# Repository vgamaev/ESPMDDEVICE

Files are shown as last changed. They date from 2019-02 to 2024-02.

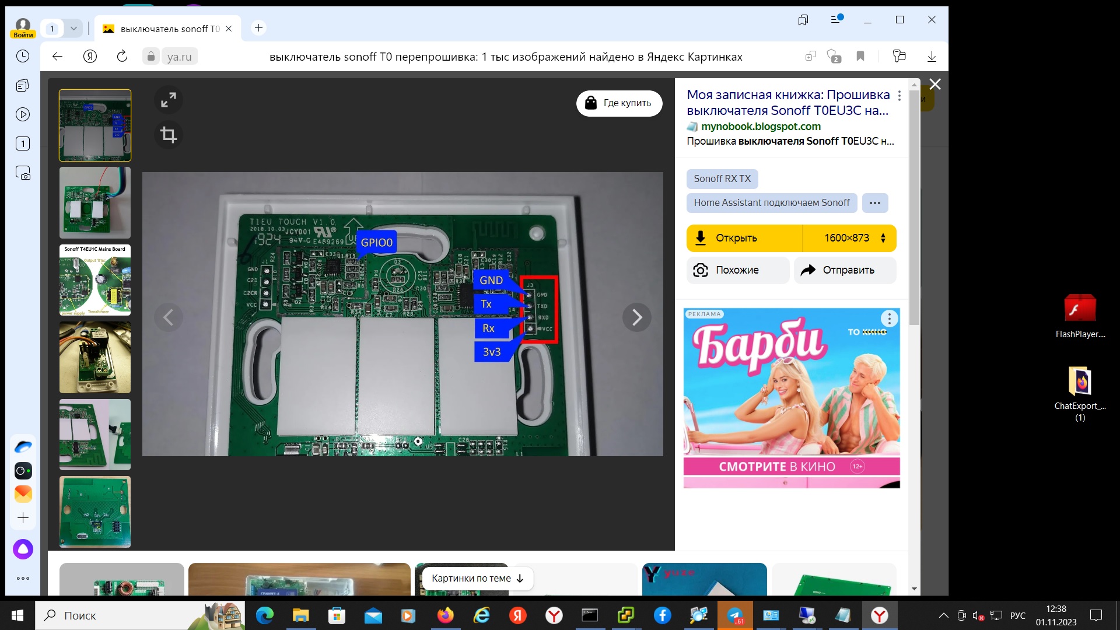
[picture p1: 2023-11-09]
Build/Перепрошивка/SonOff T0.jpg

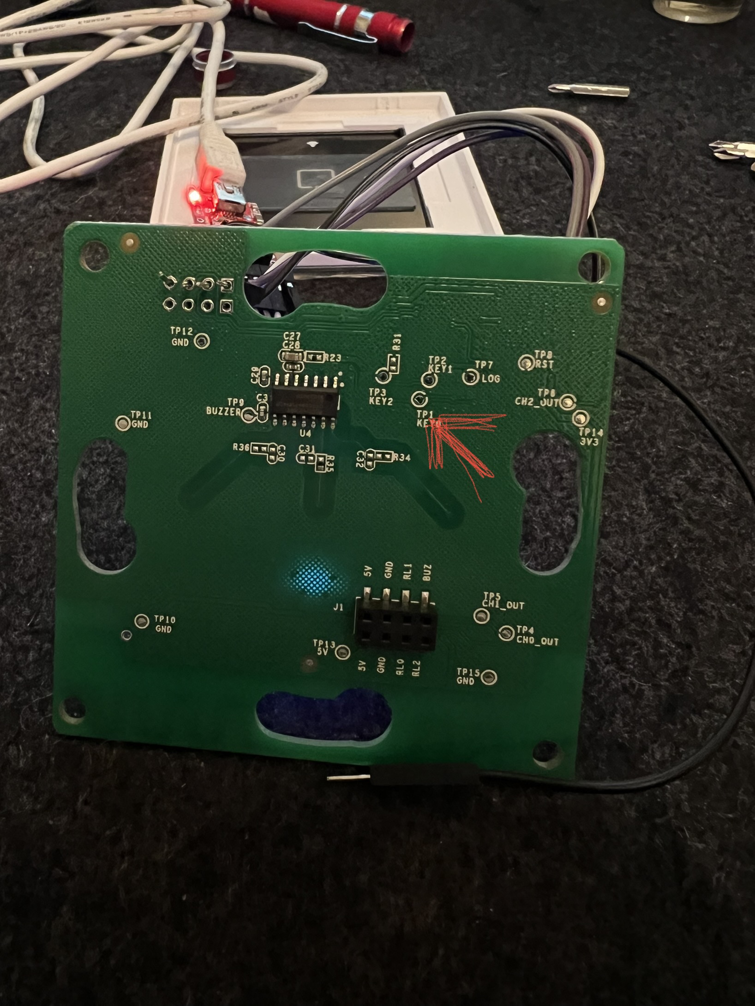
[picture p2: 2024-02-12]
Build/Перепрошивка/201542789-d46a310b-ffff-4856-8f7d-acfa5a5eafc3.jpg

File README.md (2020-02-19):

ESPMDDEVICE
Developed ESP8266 MajorDomo device

ESPMDDEVICE  
  Developed ESP8266 MajorDomo device  
Что реализовано.  
- Включение выключение лампочки через MojorDoMo, встроенную вэб страницу, кнопкой на устройстве.  
- Передача состояния лампы в MojorDoMo.  
- Конфигурация устройства через встроенный вэб интерфейс  
- Начальная конфигурация через встроенную точку доступа.  
- Запись конфигурации во внутреннею  EEPROM  
- Запрос логина и пароля для доступа к встроенной вэб странице. 
- ИК пприемник.передатчик.
- Измерение уровня освещености.
- Добавил поддержку выключателей Sonoff T1 двух, трехкнопочный, Sonoff Touch,  розетка Sonoff S20, 
- Поддержка информера на светодиодных матрицах 8x8 на микросхеме MAX7219 с поддержкой русского языка.
- Обновление прошивки через WEB интерфейс на esp8266 c flash памятью больше 1 мб.
- Ихмерение температуры и влажности датчиком DHT22 и ему подобным.
- Управление зановесками (карнизом).
- Считывания показаний счетчика Энергомера СЕ102М и ему подобным.

Библиотеки для сборки кода https://github.com/vgamaev/lib
Скрипты интеграции с MajorDomo
https://connect.smartliving.ru/profile/907/objects.html

Управления реле 
http://192.168.1.11/relay?token=12345678&relay=3&state=off  
Строка которую отправляет выключатель для изменения состояния лампы в MajorDoMo.  
http://192.168.43.218/objects/?object=LAMP1&op=set&p=status&v=0   где v=1 лампа включена v=0 лампа выключена.  

Форум выключатель https://majordomo.smartliving.ru/forum/viewtopic.php?f=8&t=3071&p=35666
ИК передатчик https://majordomo.smartliving.ru/forum/viewtopic.php?f=6&t=4670

Информер
Отправка строки на информер 192.168.1.42/informer?token=123456&bright=10&power=0&priority=high&string=привет
	bright - ярость от 0-15
	power  - отключить дисплей 1, включить дисплей 1.
	priority=high  сообщение выводится сразу, не дожидаясь пока закончится отображение предедущегою
Опции можно отправлять отдельно.

23.01.2020
Уравление зановесками (электро карниз)
Прнциа управления, мотор кулючается на время за которое зановеска проходит необходимое растоняние, задается параметром Open time sec: в настройках.

WEB API
Управление положением зановески http://IP_address/karniz?token=token&position=25
Установка текущего положения карниза (калибровка), и время открытия карниза (длина) http://IP_address/karniz?token=token&calibrate=11&opentime=18

Драйвер мотора L298N плата с али.
Редуктор с али червячный на 62 оборота в минуту.
Чертежи миханики прилогаются в исходниках.
Контакты Модуля ESP-12 для управления L298N
IN1 = 16 IN2 = 14

1б.02.2020
Считывания показаний счетчика Энергомера СЕ102М и ему подобным (требует тестирования)
Считывание происходит через оптопорт, как сделать оптопорт https://mjdm.ru/forum/viewtopic.php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
Считываемые параметры:
	- Текущее потребление
	- Нагрузку в киловаттах 
	- Ток.
	Напряжение сети.
	- астоту сети.
Передает показания на сервер MajorDomo через HTTP запросы, заполняя свойства объекта заданного в настройках устройства.

19.04.2019
Пояснения по сборке.
Из этого кода можно с генерировать прошивку для разных девайсов, например выключатели, ик прием-передатчик, информер, управление занавесками и д.р.
Для какого именно девайса и доп функции для девайса, например термометр задаются комментированием строк //
в файле ESPMDDEVICE.h https://github.com/vgamaev/ESPMDDEVICE/ ... MDDEVICE.h
Пины которые требуются для девайса задаются в файле MAINVARIABLE.h https://github.com/vgamaev/ESPMDDEVICE/ ... VARIABLE.h
Либо в *.H файлах связанных с функционалом конкретного девайса (исторически сложилось, код пишу не один год)

Пароль от точки доступа wi-fi 66666666
Логин для доступа к web интерфейсу admin
Пароль esp8266

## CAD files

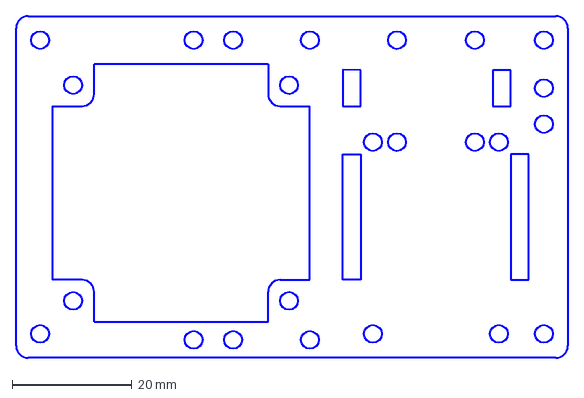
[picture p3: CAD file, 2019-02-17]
Build/Karniz/Controler.dxf
92.0 x 57.0 mm

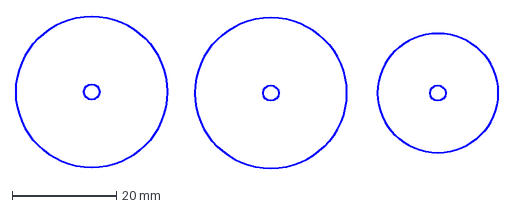
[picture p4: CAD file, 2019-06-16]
Build/Karniz/mexanic/Chkiv.dxf
92.4 x 29.2 mm

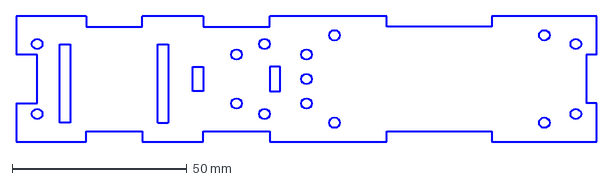
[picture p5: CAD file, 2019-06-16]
Build/Korpus/CNC/CNC_led_Matrix2_PCB.dxf
166.0 x 36.0 mm

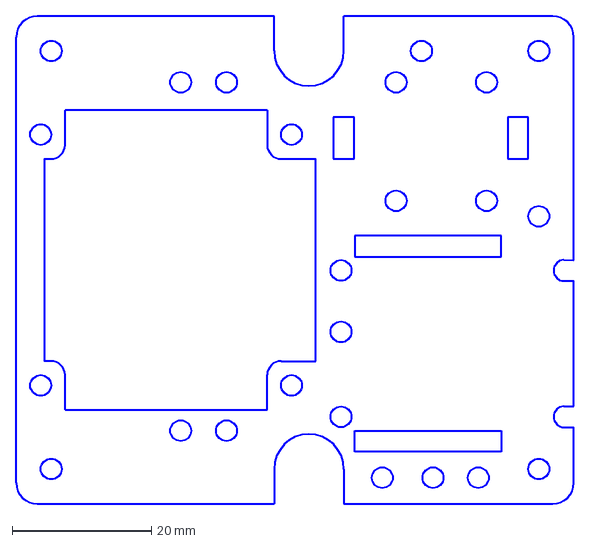
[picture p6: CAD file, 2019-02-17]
Build/Karniz/Controler2.dxf
80.0 x 70.0 mm

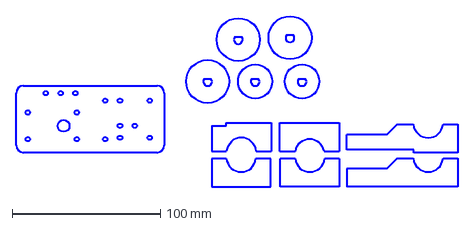
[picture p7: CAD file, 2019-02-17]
Build/Karniz/mexanic/CarnizV2.dxf
297.7 x 114.8 mm

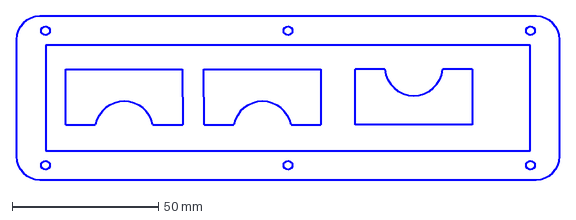
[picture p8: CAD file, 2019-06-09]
Build/Korpus/CNC/CNC_led_Matrix2_2.dxf
186.0 x 56.0 mm

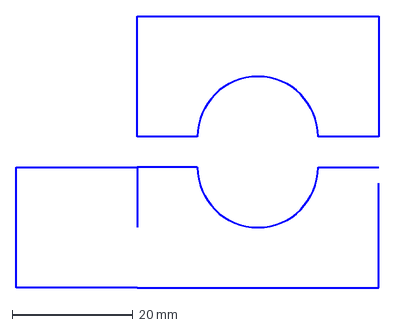
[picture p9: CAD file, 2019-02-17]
Build/Karniz/mexanic/Carniz.dxf
60.0 x 45.0 mm

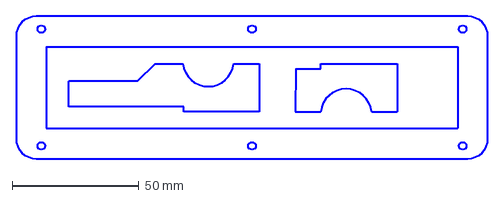
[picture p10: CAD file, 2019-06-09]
Build/Korpus/CNC/CNC_led_Matrix1.dxf
186.0 x 56.0 mm

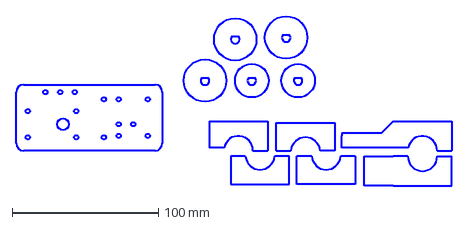
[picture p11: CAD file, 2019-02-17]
Build/Karniz/mexanic/karniz.dxf
297.8 x 115.8 mm

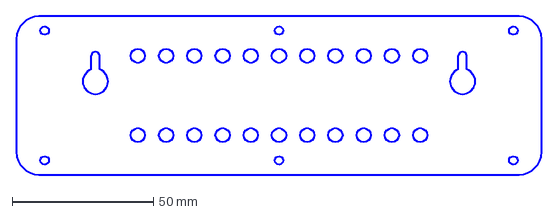
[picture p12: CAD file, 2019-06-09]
Build/Korpus/CNC/CNC_led_Matrix2_4.dxf
186.0 x 56.0 mm

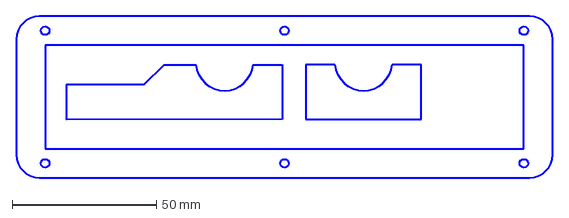
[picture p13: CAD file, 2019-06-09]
Build/Korpus/CNC/CNC_led_Matrix2_1.dxf
186.0 x 56.0 mm

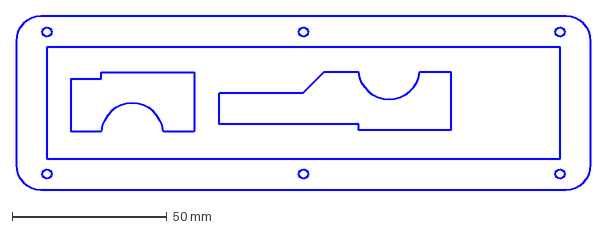
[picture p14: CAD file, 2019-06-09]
Build/Korpus/CNC/CNC_led_Matrix2_3.dxf
186.0 x 56.0 mm

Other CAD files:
Build/Energomera/Reader/corp.dwg

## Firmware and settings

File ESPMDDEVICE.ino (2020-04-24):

#include "MAINVARIABLE.h"

//==============================================================================
unsigned long StrToULong(char *str)
{
 int len = strlen(str);
 unsigned long res = 0;
 unsigned long mul = 1;
 for(int i = len - 1; i >= 0; i--){
  res += mul * (unsigned long)(str[i] - '0');
  mul *= 10;
 }
 return res;
}

//===========================================================================================

void setup(void) {
  #ifdef RELAYS_ON
    RelayInit();
    ButtonInit();
    web_button_state_init();
  #endif
  #ifdef WIFI_LED
    pinMode(WIFI_led,OUTPUT);
    digitalWrite(WIFI_led, HIGH);           //Выключаем пин чтобы не мигала при старте
  #endif
    
  Serial.begin(9600);
  delay(10);

  //Записываем дефолтную конфигурацию
  DeraultConfig();
  
  // Читаем конфигурацию с EEPROM
  ConfigRead();

  // Включаем точку доступа инециализируем WIFI
  WiFi.hostname(Config.name);
  EnableAP();  
  ConectWIFI();

  Serial.println("Starting");
    
  // Назначем функции на запросы
  server.on("/setup", handleSetup);
  server.on("/", handleRoot);

  #ifdef BUTTON2
    ButtonInit2();
  #endif 
  
  #ifdef RELAYS_ON
    server.on("/on", handleOn);
    server.on("/off", handleOff);
    server.on("/relay", handleRelay);
  #endif
  #ifdef IR_RESIVER 
    server.on("/ir",  handleIR);
    //Стартуем ИК приемопередатчик
    StartIR();
  #endif
  #ifdef LED_MATRIX 
    server.on("/informer",  handleLedMatrix);
    LedMatrixInit();
  #endif
  #ifdef RF433MHZ
    Start433();
  #endif
  #ifdef DHT22
    dhtInit();
  #endif
  
  #ifdef KARNIZ
    server.on("/karniz",  handleKarniz);
    InitKarniz();
  #endif

  #ifdef ENERGOMERA
    EnergomeraInit(); 
  #endif

  #ifdef ADC
    ADCInit();
  #endif
  
  #ifdef WEBUPDATE
    server.on("/webupdate", HTTP_GET, handleWebUpdate);
    server.on("/update", HTTP_POST, handleUpdate1, handleUpdate2);
  #endif
  server.onNotFound(handleNotFound);
  
  // Стартуем WEB сервер
  server.begin();

}

void loop(void) {
  server.handleClient();
  WiFiLedStatus();
  #ifdef ADC
    adcRead();  // читаем вход ацп
  #endif

  #ifdef BUTTON2
    ButtonSwitch2();
  #endif  
  
  #ifdef IR_RESIVER 
    IRResiver();
  #endif
  #ifdef RELAYS_ON
    ButtonSwitch();
  #endif
  #ifdef LED_MATRIX
    LedMatrix();
  #endif
  #ifdef RF433MHZ
    Resiver433();
  #endif
  #ifdef DHT22
    dhtRead();
  #endif
  #ifdef KARNIZ
    KarnizWork();
  #endif
  #ifdef ENERGOMERA
    EnergomeraCycle();
  #endif
}

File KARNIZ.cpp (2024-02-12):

#include "KARNIZ.h"

#ifdef KARNIZ

//Обрабатываем ВЕБ запросы
void handleKarniz()
{
    String buf = server.arg("token");
    Serial.println(buf);
  
    if (Config.www_password != buf) {
      String message = "access denied";
      server.send(401, "text/plain", message);
      return;
    }
    buf = server.arg("position");
    char b[3];
    if(buf.length())
    {
      buf.getBytes((unsigned char *)b, 4);
      //KarnizPosition
      int a = (int)StrToULong(b);
      if(a >= 0 && a <=100)
      {
          Serial.print("WEB KarnizPosition ");
          Serial.println(a);
          KarnizPosition = map(a,0,100,0,KarnizLength);
          Serial.println(KarnizPosition);
      } else Serial.print("ERROR position");
    }

    buf = server.arg("calibrate");
    if(buf.length())
    {
      buf.getBytes((unsigned char *)b, 4);
      int Q = (int)StrToULong(b);
      if(Q >= 0 && Q <=100)
      {
          Serial.print("Calibrate CurKarnizPosition ");
          Serial.println(Q);
          CurKarnizPosition = map(Q,0,100,0,KarnizLength);
          Serial.println(CurKarnizPosition);
          KarnizPosition = CurKarnizPosition;
      } else Serial.print("ERROR calibrate");
      
    }

    buf = server.arg("opentime");
    if(buf.length())
    {
      buf.getBytes((unsigned char *)b, 3);
      int z = (int)StrToULong(b);
      if(z >= 0 && z <=100)   //Время открытия карниза
      {
        KarnizLength = z;
        Serial.print("WEB open time second ");
        Serial.println(KarnizLength);
      }else Serial.print("ERROR opentime");
    }

    
     String message = "success";
    server.send(200, "text/plain", message);  
}

void InitKarniz() {
  // set all the motor control pins to outputs
  //pinMode(ENA, OUTPUT);
  pinMode(IN1, OUTPUT);
  pinMode(IN2, OUTPUT);
  digitalWrite(IN1, LOW);
  digitalWrite(IN2, LOW);
  ReadEPROMKarnizLength();
  Serial.println();
  Serial.println("Init karniz...");
  VersionCode += VersionKARNIZ ;
//  ReadCurPosMD();
}


//обрабатываем нажатые кнопки
void KarnizButtonSwitch(int nomer)
{   
    switch(nomer)
    {
      case 0:
          OpenCloseKarniz();
      break;

      case 1:

      break;
    }
}

void OpenCloseKarniz()
{
    // Допустим время открутие карниза 8 секунд, у управление карниза 0-100, п этому нужно конвертировать
    int a = map(CurKarnizPosition,0,KarnizLength,0,100);
     //if(CurKarnizPosition >= 50) KarnizPosition = 100;
     //else if(CurKarnizPosition < 50) KarnizPosition = 0;
     if(a >= 50)  KarnizPosition = 0;
     else if(a < 50) KarnizPosition = map(100,0,100,0,KarnizLength); // Выстовляем саксимальное открытие карниза
     Serial.println("Func Open Close Karniz ");
     Serial.println(KarnizPosition);
}


void ReadEPROMKarnizLength()
{
  //Читаем длину карниза еи eeprom
  char KarnizLengthChar[Config.KarnizLength.length()+1];
  Config.KarnizLength.toCharArray(KarnizLengthChar,Config.KarnizLength.length()+1);
  int z = (int)StrToULong(KarnizLengthChar);
  KarnizLength = z;
  Serial.println(z);
  Serial.print("Dlina karniza iz eeprom ");
  Serial.println();

}

void MotorForward()
{
  if(KarnizMotorState != 1)
  {
    //digitalWrite(ENA, HIGH); // set speed to 200 out of possible range 0~255
    digitalWrite(IN1, HIGH);
    digitalWrite(IN2, LOW); 
    Serial.println("Motor forward...");
    KarnizMotorState = 1;
  }
}

void MotorBackward()
{
  if(KarnizMotorState != 2)
  {
    //digitalWrite(ENA, HIGH); // set speed to 200 out of possible range 0~255
    digitalWrite(IN1, LOW);
    digitalWrite(IN2, HIGH);
    Serial.println("Motor backward...");
    KarnizMotorState = 2;
  }
}

void MotorStop()
{
  if(KarnizMotorState > 0)
  {
    digitalWrite(IN1, LOW);
    digitalWrite(IN2, LOW);
    SendCurKarnizPosition();
    Serial.println("Motor stop...");
    KarnizMotorState = 0;
  }
}

void KarnizWork()
{
    static long previousMillis = 0;
    long KarnizCurrentMillis = millis();
    static long motorDelay = 1;
    static int f = 0;
    static int g = 1000;

    if(KarnizCurrentMillis - previousMillis > 1000) 
    {
      previousMillis = KarnizCurrentMillis;
      Serial.print("KarnizPosition ");
      Serial.println(KarnizPosition);
      Serial.print("CurKarnizPosition ");
      Serial.println(CurKarnizPosition);

      if(f < 10) // Пробуем почитать текущию позицию карниза с сервера в течении 10 секунд после старта
      {
        if(CurKarnizPosition == 0)
        {
           ReadCurPosMD();
           f++;
        }else f = 10;
      } 
      else if(KarnizPosition == CurKarnizPosition || KarnizPosition > KarnizLength) 
            {
              MotorStop(); //останавливаем мотор
              motorDelay = 1;
            }
            else if(KarnizPosition > CurKarnizPosition)
                 {
                    if(motorDelay < 2) {    // нужно подождать пока мотор остановится при резкой смене напрвления
                      MotorStop();
                      motorDelay ++ ;
                    }
                    else {
                      MotorForward();
                      CurKarnizPosition ++ ;
                    }
                 }
                else if(KarnizPosition < CurKarnizPosition)
                {
                   if(motorDelay > 0) {     // нужно подождать пока мотор остановится при резкой смене напрвления
                      MotorStop();
                      motorDelay -- ;
                    }
                   else {
                      MotorBackward();
                      CurKarnizPosition -- ;
                   }
               }
    }       
}

void SendCurKarnizPosition()
{
     int a = map(CurKarnizPosition,0,KarnizLength,0,100);
     //String post = "http://"+Config.serverIP+"/objects/?object="+Config.name+"&op=set&p=slider2&v="+a;
     String post = "http://"+Config.serverIP+"/objects/?object="+Config.name+"&op=set&p="+Config.property+"&v="+a;
     Serial.println(post);
     Serial.println(post);
     http.begin(client, post);
     int httpCode = http.GET(); 
     http.end();
}

void ReadCurPosMD()
{
  String post = "http://"+Config.serverIP+"/objects/?op=m&object="+Config.name+"&m=StartPos";  
        Serial.println(post);
        http.begin(client, post);
        int httpCode = http.GET(); 
        http.end();
}
/*
void KarnizCommand(int Command, int MotorDelay)
{
  KarnizMotorCommand = Command;
  KarnizMotorDelay = MotorDelay;
} */

#endif

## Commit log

2016-10-09 9.10.2016_1
    Выделил функции работы с wifi в отдельный файл
2016-10-09 9.10.2016_2
    Вынес генерацию веб страниц в отдельный файл
2016-10-10 10ю10ю2006_2
2017-11-13 13.11.2017
    Добавляем три реле
2017-11-14 14.11.2017
    Добавляю потдержку 3 кнопок для Sonoff T1
2017-12-04 4.12.2017
    Work 3 button to web interface
2017-12-05 5.12.2017
    игп ашч
2017-12-05 6.12.2017
    Bug Fix AP
    [ESPWEB.cpp, ESPWIFI.cpp]
2018-06-08 ledmatrix bug fix
2019-02-26 26022019
    Управление карнизом от 0-100 процентов вмсто времени от 0-16 секунд
2019-04-19 10042018
    Документирование.
2020-01-21 21012020
    Доработка под кнопку карниза
2020-01-21 2101020
    Максимальное время карниза увеличил до 90 секунд, иначе медленый редуктор не успевает
2020-01-21 21012020
    Добавляю сохранение времени открытия карниза в eeprom
2020-01-23 23012020
    button bug debug
    [BUTTON.cpp, KARNIZ.cpp]
2020-02-17 17022020
    Bug fix struct
    [ENERGOMERA.cpp, MAINVARIABLE.h]
